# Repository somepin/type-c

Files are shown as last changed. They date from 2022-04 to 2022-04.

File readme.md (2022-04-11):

# Type C (like the USB)

A tented columnar staggered handwired keyboard. It has a [Le Chiffre](https://github.com/tominabox1/Le-Chiffre-Keyboard)-ish layout with a 4.5° tenting angle. The case angle is 7° since it reuses the bottom piece of the [new Le Chiffre case](https://github.com/tominabox1/Le-Chiffre-Keyboard/tree/master/Cases/New%20Case).

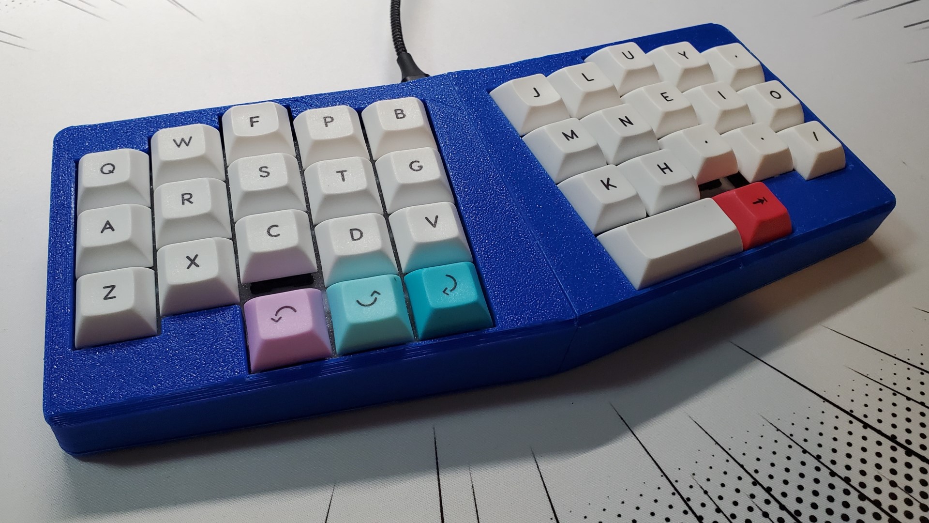
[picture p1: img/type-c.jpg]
Type C Keyboard


## Project Structure

The `split` and `nonsplit` folders have STLs for printing based on print bed size. Note the `nonsplit` case is untested.

## Components

| Part | Quantity |
| --- | --- |
| Keycaps | |
| Switches | 35 |
| Diodes (1N4148/1N4001) | 35 |
| Hookup Wire | |
| M2 Screws | 12 |
| M2 Heat Set Inserts | 12 |
| 8mm Rubber Bumpons | 4 |
| Pro Micro or Clone | 1 |

## Assembly Notes

The case has dual 4mm top mounted plates, designed around [M2x6x3.5mm heat set inserts](https://www.amazon.com/dp/B08ZHCWQ2K). The plate STLs can be flipped horizontally based on bottom row preferences, but the firmware would have to be rewritten accordingly. The Pro Micro can also be hot glued to the top of the case for added stability.

If printing the `split` case, each divided piece is held together with super glue. The top face of the top pieces should also be printed face down on the print bed to save on support material.

## Firmware & Wiring

QMK Firmware files are included as a starting point, but compile and flash the firmware based on your matrix and keymap preferences.

### Wiring/Matrix Diagram

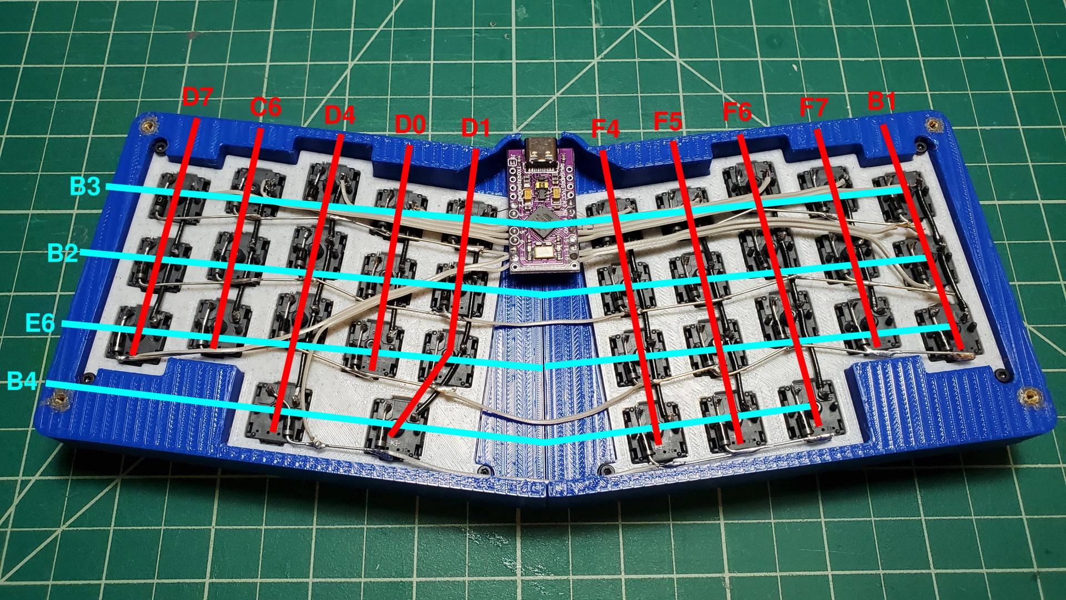
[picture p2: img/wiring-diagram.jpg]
Matrix/Wiring


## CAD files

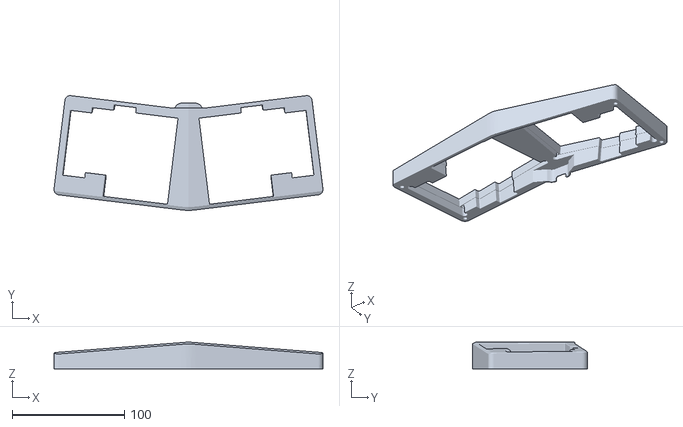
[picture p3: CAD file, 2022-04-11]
nonsplit/top.stl
239.4 x 102.1 x 24.0

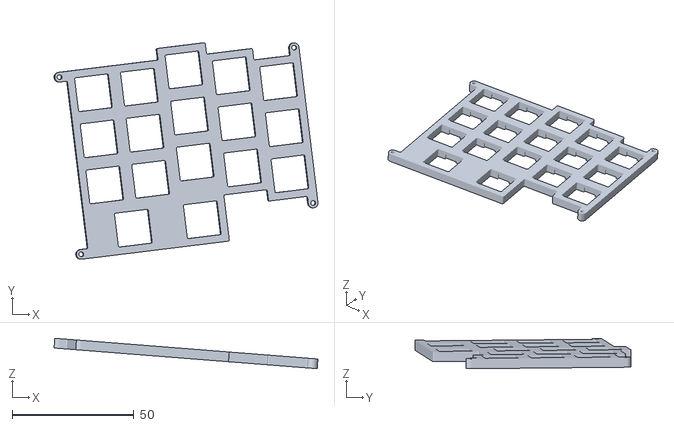
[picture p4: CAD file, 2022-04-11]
plate/right.stl
108.3 x 88.8 x 12.5

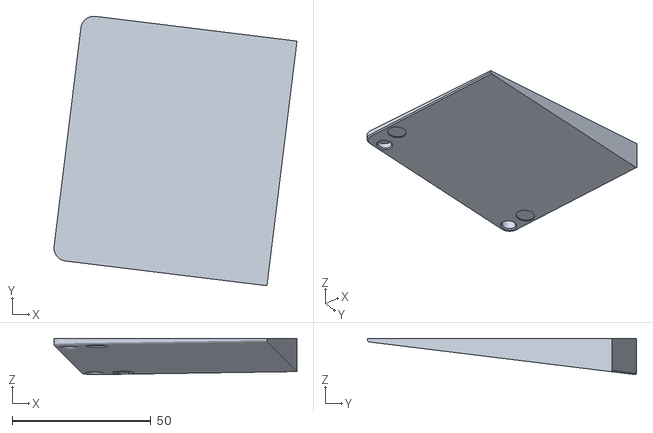
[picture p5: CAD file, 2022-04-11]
split/bottom-left.stl
87.7 x 97.3 x 13.1

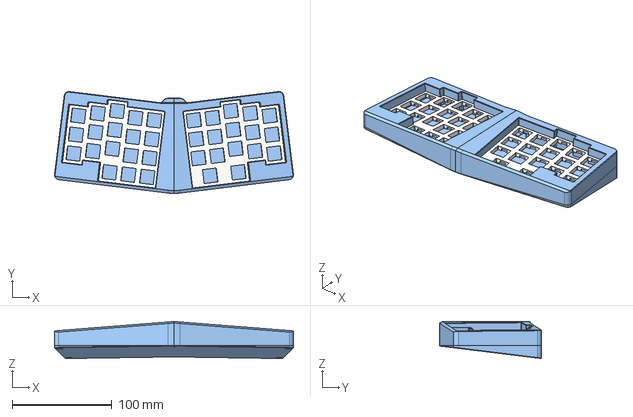
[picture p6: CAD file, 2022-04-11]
type-c.step
239.5 x 102.1 x 37.1 mm

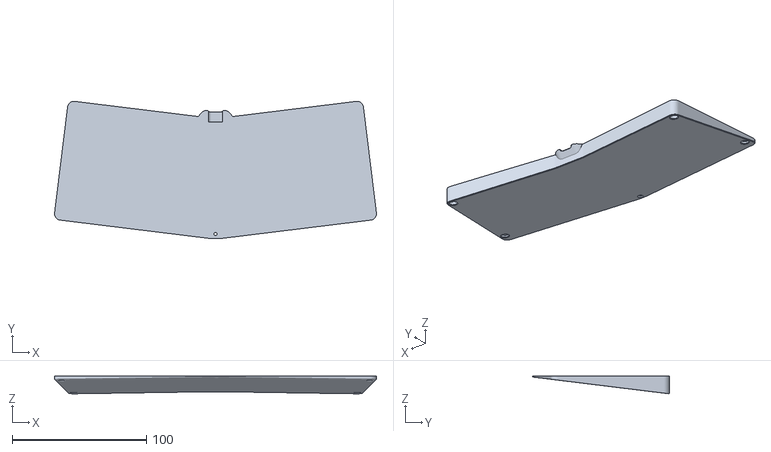
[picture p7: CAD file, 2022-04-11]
nonsplit/bottom.stl
239.5 x 102.1 x 13.1

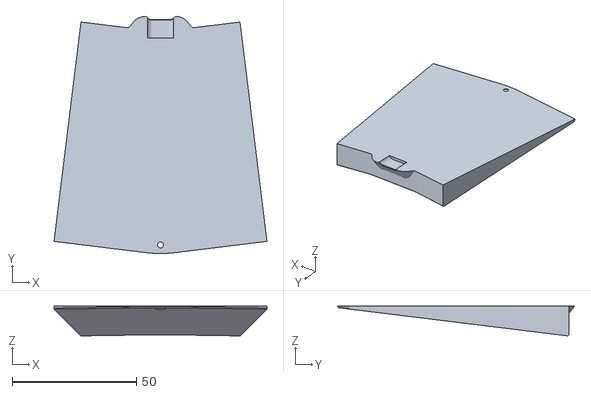
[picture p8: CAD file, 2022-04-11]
split/bottom-mid.stl
85.7 x 95.4 x 12.0

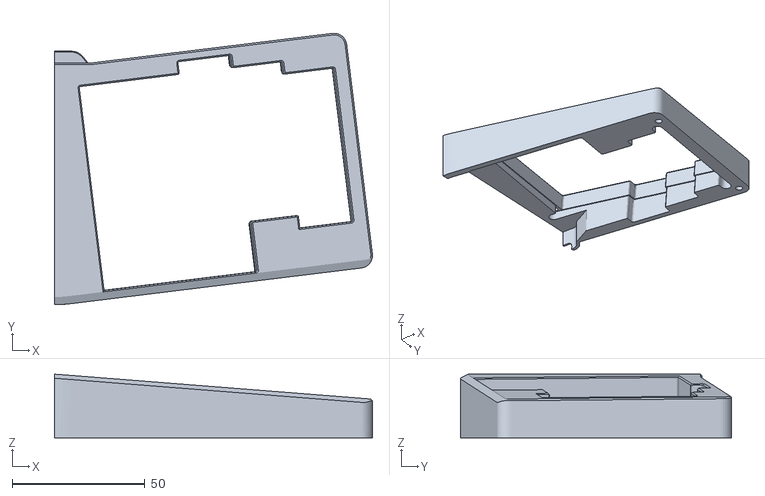
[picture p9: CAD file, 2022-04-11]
split/top-right.stl
119.7 x 102.1 x 24.0

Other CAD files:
plate/left.stl
split/bottom-right.stl
split/top-left.stl
